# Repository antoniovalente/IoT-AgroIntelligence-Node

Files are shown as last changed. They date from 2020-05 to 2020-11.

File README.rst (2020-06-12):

IoT AgroIntelligence LoRaWAN Node
=================================

PCB files of a LoRaWAN node for agriculture use. The node uses a
`CubeCell module from Heltec <https://heltec.org/project/htcc-ab01/>`__.
The node has four 12-bit ADC channels, one 18-bit ADC channel, one I2C
port, and one SDI-12 port. It is also possible to connect a 3.6V LiPo
battery and the node has an onboard solar energy management system, that
can directly connect with a 5.5~7V solar panel.

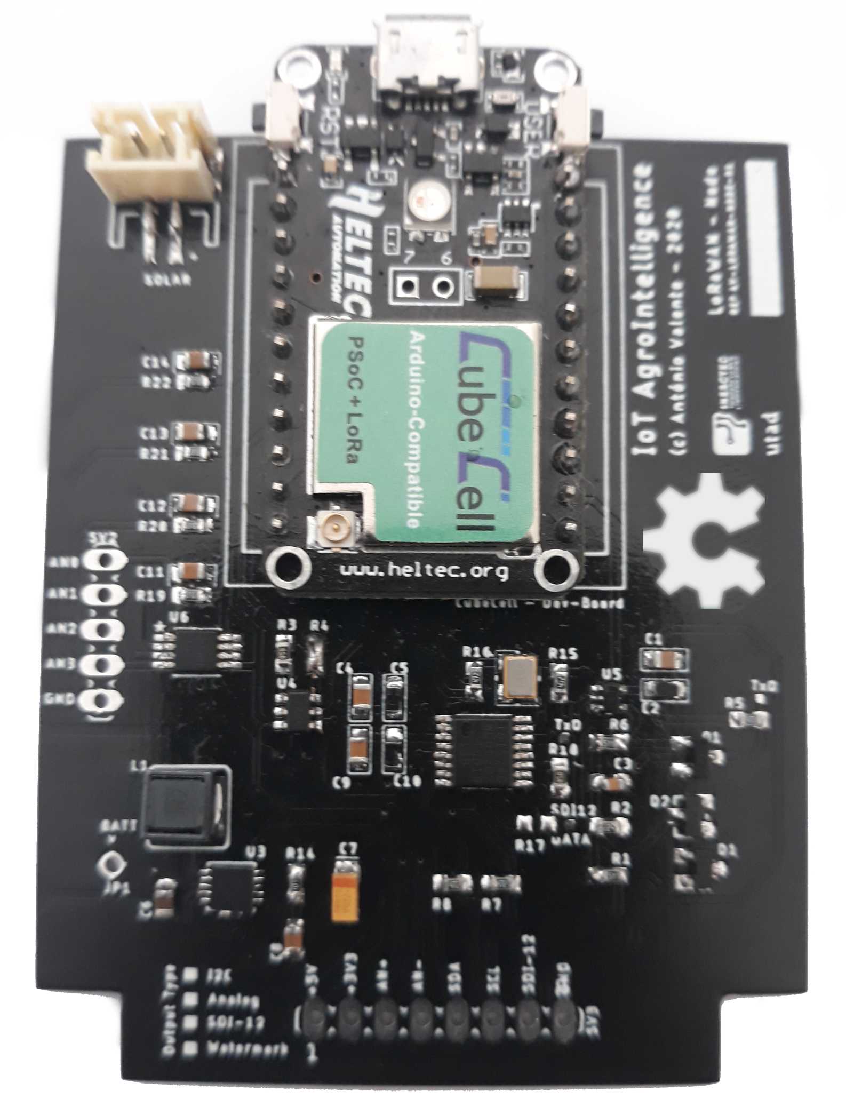
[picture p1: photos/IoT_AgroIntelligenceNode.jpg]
IoT Node


IoT Node Prerequisites
~~~~~~~~~~~~~~~~~~~~~~~

To view the files use Autodesk Eagle (project uses version 9.6.0)

`Autodesk
Eagle <https://www.autodesk.com/products/eagle/free-download>`__

Authors
-------

-  **Antonio Valente** - *Initial work* - `Antonio
   Valente <https://github.com/antoniovalente/>`__

.. raw:: html

   <!---See also the list of [contributors](https://github.com/your/project/contributors) who participated in this project. --->
   
Articles
--------
MDPI Electronics `"Low-Cost LoRaWAN Node for Agro-Intelligence IoT" <https://www.mdpi.com/741896>`__

Licenses
--------

The hardware project is licensed under the `CERN Open Hardware
Licence <https://ohwr.org/cernohl>`__ - see the
`LICENSE.md <LICENSE.md>`__ file for details.

The documentation files are licensed under a `Creative Commons
Attribution 4.0 International
License <http://creativecommons.org/licenses/by/4.0/>`__ - see the
`LICENSE-CC-BY.md <LICENSE.md>`__ file for details





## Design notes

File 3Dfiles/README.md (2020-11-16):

Boxes, lids and hoses for LoRaWAN sensor devices
================================================

BOX.stl file for 3D printing a BOX with the 1st HOSE for IoT-AgroIntelligence Node (LoRaWAN sensor node for agriculture) with solar panel and battery.

LID.stl file for 3D printing the LID for the BOX in BOX.stl.

HOSE_SENSOR_03.stl file for 3D printing the HOSE for sensors like BME680.

BOX_WisBlock.stl file for 3D printing the BOX for Wisblock board with RAK1920 (with Mickroe SDI-12 board). The BOX has two holes: TOP for antenna (RS:125-1251) and botton for EN3P4MX connector (EN3 séries Dig-Key:SC263-ND). A 18650 lithium battery holder also fits in the box.

HOSE_03.stl and HOSE_04.stl files for 3D printing the HOSES for a flexible hose to house ambient sensors (like BME680). The two files have different tolerances.

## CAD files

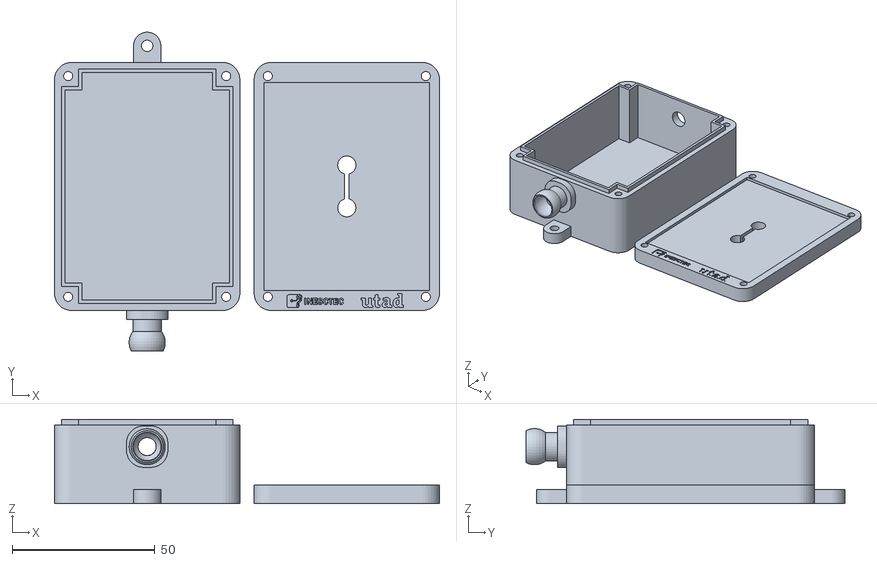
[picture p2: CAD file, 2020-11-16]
3Dfiles/CompleteBOXwoHorse.stl
135.0 x 111.7 x 29.6

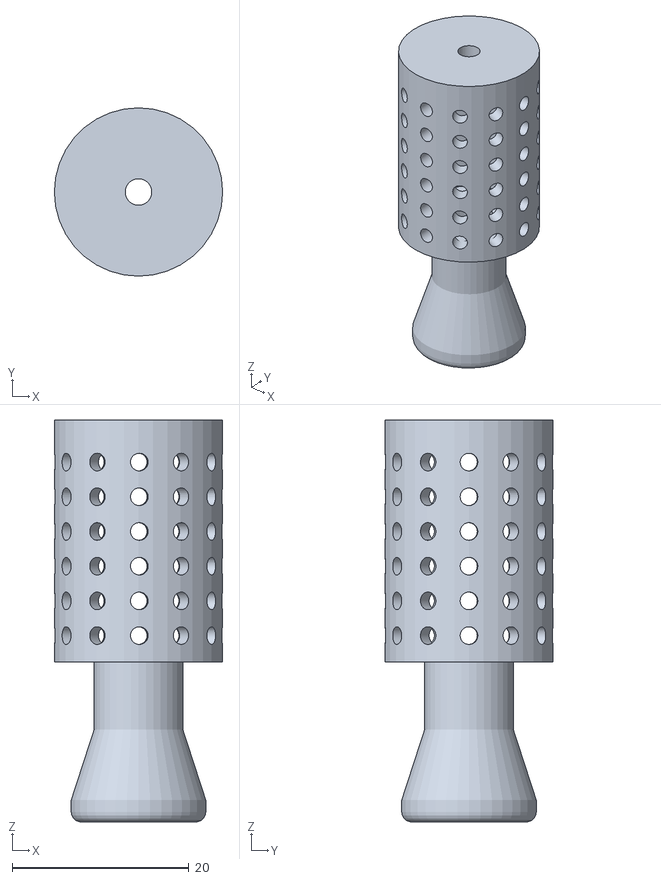
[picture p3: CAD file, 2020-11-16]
3Dfiles/HOSE_SENSOR_03.stl
19.1 x 19.1 x 45.5

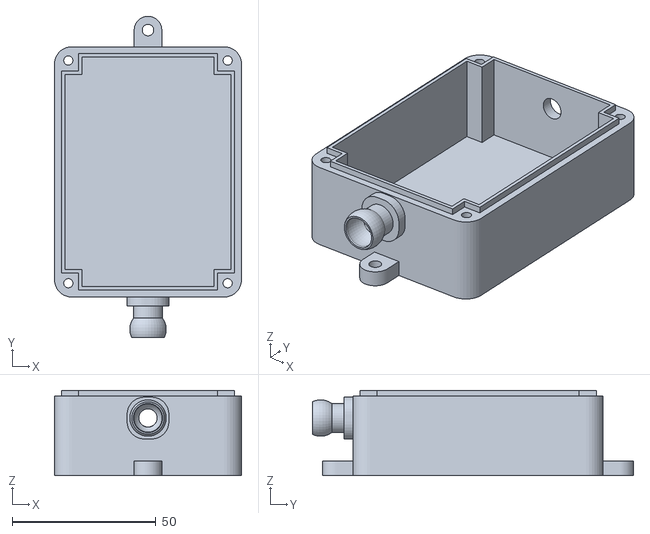
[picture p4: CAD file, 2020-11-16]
3Dfiles/BOX.stl
65.0 x 111.7 x 29.6

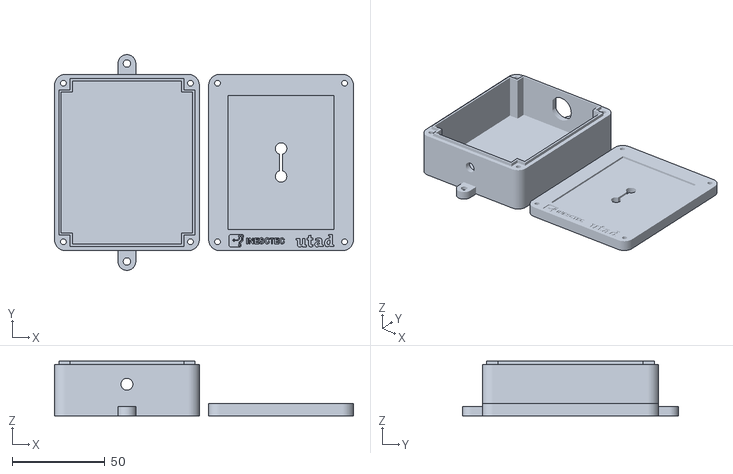
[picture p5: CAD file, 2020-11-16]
3Dfiles/BOX_WisBlock.stl
161.0 x 116.2 x 29.6

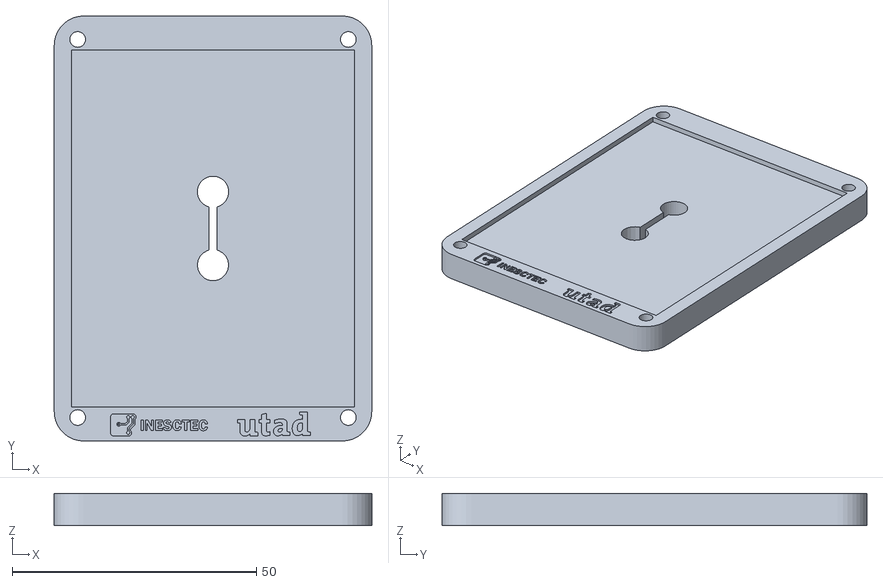
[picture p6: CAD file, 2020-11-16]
3Dfiles/LID.stl
65.0 x 87.0 x 6.60

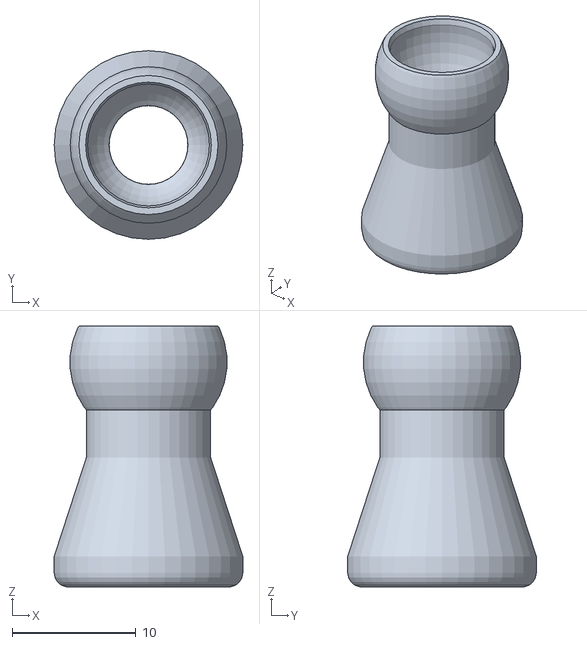
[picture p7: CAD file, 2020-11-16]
3Dfiles/HOSE_03.stl
15.2 x 15.2 x 21.1

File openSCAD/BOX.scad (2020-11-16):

include <Parametric_Modular_Hose_Library_v02/modularHoseLibrary.scad>

/* [Box Options] */
// Dimension: Box outer X-Size [mm] 72
box_Size_X          = 78;
// Dimension: Box outer Y-Size [mm]
box_Size_Y          = 95;
// Dimension: Box Inner height [mm]
box_Inner_Height    = 25;
// Box bottom/top thickness
box_BottomTop_Thickness =  2.6; // [0.6:0.2:3]
// Edge corner radius 
box_Screw_Corner_Radius   =  6; // [2:1:10]
// four outer screw hole diameters
box_Screw_Diameter     =  3.1; // [2:0.2:4]
// Box wall thickness
box_Wall_Thickness     =  3.6; // [0.4:0.2:3.2]
/* [Top Barrier Options] */
// Box barrier thickness
barrier_Thickness  =  1.2; // [0.4:0.2:3.2]
// Box barrier height
barrier_Height     =  2;   // [1.0:0.2:8]
// Additional width on the lid to correct for badly calibrated printers
barrier_Tolerance  =  0.8; // [0.0:0.1:1]
/* [Mouting Screw Nose Options] */
// Number of screw noses
screwnose_Number        = 2; // [0:No noses, 2: one top/one bottom, 4: two top/two bottom]
// Diameter of the noses' screw holes
screwnose_Diameter      = 4; // [2:0.2:8]
// Height of the noses
screwnose_Height        = 5; // [2:0.2:10]
// Wall thickness
screwnose_Wall_Thickness = 2.8; // [2:0.2:5]

// Solar panel
panel_Size_X            = 58;

panel_Size_Y            = 73;

panel_Height            = 2.5;
// **************************
// ** Calculated globals
// **************************
boxHeight = box_Inner_Height+box_BottomTop_Thickness;

module box() {
	barrier_Thickness = box_Wall_Thickness-barrier_Thickness;
	difference() {
		union() {
			// solid round box, corners
			translate([box_Screw_Corner_Radius, box_Screw_Corner_Radius, 0]) cylinder(r=box_Screw_Corner_Radius, h=boxHeight, $fn=definition); // bottom left
			translate([box_Size_X-box_Screw_Corner_Radius, box_Screw_Corner_Radius, 0]) cylinder(r=box_Screw_Corner_Radius, h=boxHeight, $fn=definition); // bottom right
			translate([box_Screw_Corner_Radius, box_Size_Y-box_Screw_Corner_Radius, 0]) cylinder(r=box_Screw_Corner_Radius, h=boxHeight, $fn=definition); // top left
			translate([box_Size_X-box_Screw_Corner_Radius, box_Size_Y-box_Screw_Corner_Radius, 0]) cylinder(r=box_Screw_Corner_Radius, h=boxHeight, $fn=definition); // bottom right
			// solid round box, inner filling
			translate([0, box_Screw_Corner_Radius, 0]) cube([box_Size_X, box_Size_Y-2*box_Screw_Corner_Radius, boxHeight]);
			translate([box_Screw_Corner_Radius, 0, 0]) cube([box_Size_X-2*box_Screw_Corner_Radius, box_Size_Y, boxHeight]);
			// solid round box, top border
			translate([barrier_Thickness, box_Screw_Corner_Radius+barrier_Thickness, 0]) cube([box_Size_X-2*barrier_Thickness, box_Size_Y-2*box_Screw_Corner_Radius-2*barrier_Thickness, boxHeight+barrier_Height]);
			translate([box_Screw_Corner_Radius+barrier_Thickness, barrier_Thickness, 0]) cube([box_Size_X-2*box_Screw_Corner_Radius-2*barrier_Thickness, box_Size_Y-2*barrier_Thickness, boxHeight+barrier_Height]);
		}
		// inner cut-out
		translate([box_Wall_Thickness, box_Screw_Corner_Radius+box_Wall_Thickness, box_BottomTop_Thickness]) cube([box_Size_X-2*box_Wall_Thickness, box_Size_Y-2*box_Screw_Corner_Radius-2*box_Wall_Thickness, boxHeight+barrier_Height]);
		translate([box_Screw_Corner_Radius+box_Wall_Thickness, box_Wall_Thickness, box_BottomTop_Thickness]) cube([box_Size_X-2*box_Screw_Corner_Radius-2*box_Wall_Thickness, box_Size_Y-2*box_Wall_Thickness, boxHeight+barrier_Height]);
		// Screw holes
		translate([(box_Screw_Corner_Radius+box_Wall_Thickness)/2,(box_Screw_Corner_Radius+box_Wall_Thickness)/2,-0.25]) cylinder(r=box_Screw_Diameter/2, h=boxHeight+0.5, $fn=definition);
		translate([(box_Screw_Corner_Radius+box_Wall_Thickness)/2,box_Size_Y-(box_Screw_Corner_Radius+box_Wall_Thickness)/2,-0.25]) cylinder(r=box_Screw_Diameter/2, h=boxHeight+0.5, $fn=definition);
		translate([box_Size_X-(box_Screw_Corner_Radius+box_Wall_Thickness)/2,(box_Screw_Corner_Radius+box_Wall_Thickness)/2,-0.25]) cylinder(r=box_Screw_Diameter/2, h=boxHeight+0.5, $fn=definition);
		translate([box_Size_X-(box_Screw_Corner_Radius+box_Wall_Thickness)/2,box_Size_Y-(box_Screw_Corner_Radius+box_Wall_Thickness)/2,-0.25]) cylinder(r=box_Screw_Diameter/2, h=boxHeight+0.5, $fn=definition);
		// **************************
		// ** YOUR OWN CUTOUTS HERE!
		// **************************
        // bottom
		cRadius = 7.8;
        yDisp = 1.5;
		translate([box_Size_X/2,(box_Wall_Thickness+0.1), box_Wall_Thickness+((boxHeight-box_Wall_Thickness)/2)+yDisp]) rotate([90,00,0]) cylinder(r=cRadius2, h=box_Wall_Thickness+0.3,$fn=definition);
        // top
		cRadius2 = 3.2;
		translate([box_Size_X/2,box_Size_Y+0.1, box_Wall_Thickness+((boxHeight-box_Wall_Thickness)/2)+yDisp]) rotate([90,00,0]) cylinder(r=cRadius, h=box_Wall_Thickness+0.2,$fn=definition);
        //cRadius3 = 6.1;
		//translate([box_Size_X/2,box_Size_Y+2.5, box_Wall_Thickness+((boxHeight-box_Wall_Thickness)/2)+yDisp]) rotate([90,00,0]) cylinder(r=cRadius3, h=box_Wall_Thickness+0.2,$fn=definition);
		// **************************
		// ** / CUTOUTS
		// **************************
	}
    translate([box_Size_X/2-12.05,box_Size_Y-box_Wall_Thickness,boxHeight/2-7]) cube([5,box_Wall_Thickness, 18]);
	// Lower nose(s)
	if (screwnose_Number==2) translate([box_Size_X/2, 0.001, 0]) mirror([0,1,0]) screwNose(screwnose_Diameter, screwnose_Height);
	if (screwnose_Number==4) {
		translate([box_Size_X*0.25, 0.001, 0]) mirror([0,1,0]) screwNose(screwnose_Diameter, screwnose_Height);
		translate([box_Size_X*0.75, 0.001, 0]) mirror([0,1,0]) screwNose(screwnose_Diameter, screwnose_Height);
	}
	// Upper nose(s)
	if (screwnose_Number==2) translate([box_Size_X/2, box_Size_Y-0.001, 0]) screwNose(screwnose_Diameter, screwnose_Height);
	if (screwnose_Number==4) {
		translate([box_Size_X*0.25, box_Size_Y-0.001, 0]) screwNose(screwnose_Diameter, screwnose_Height);
		translate([box_Size_X*0.75, box_Size_Y-0.001, 0]) screwNose(screwnose_Diameter, screwnose_Height);
	}
}
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

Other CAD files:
3Dfiles/HOSE_04.stl

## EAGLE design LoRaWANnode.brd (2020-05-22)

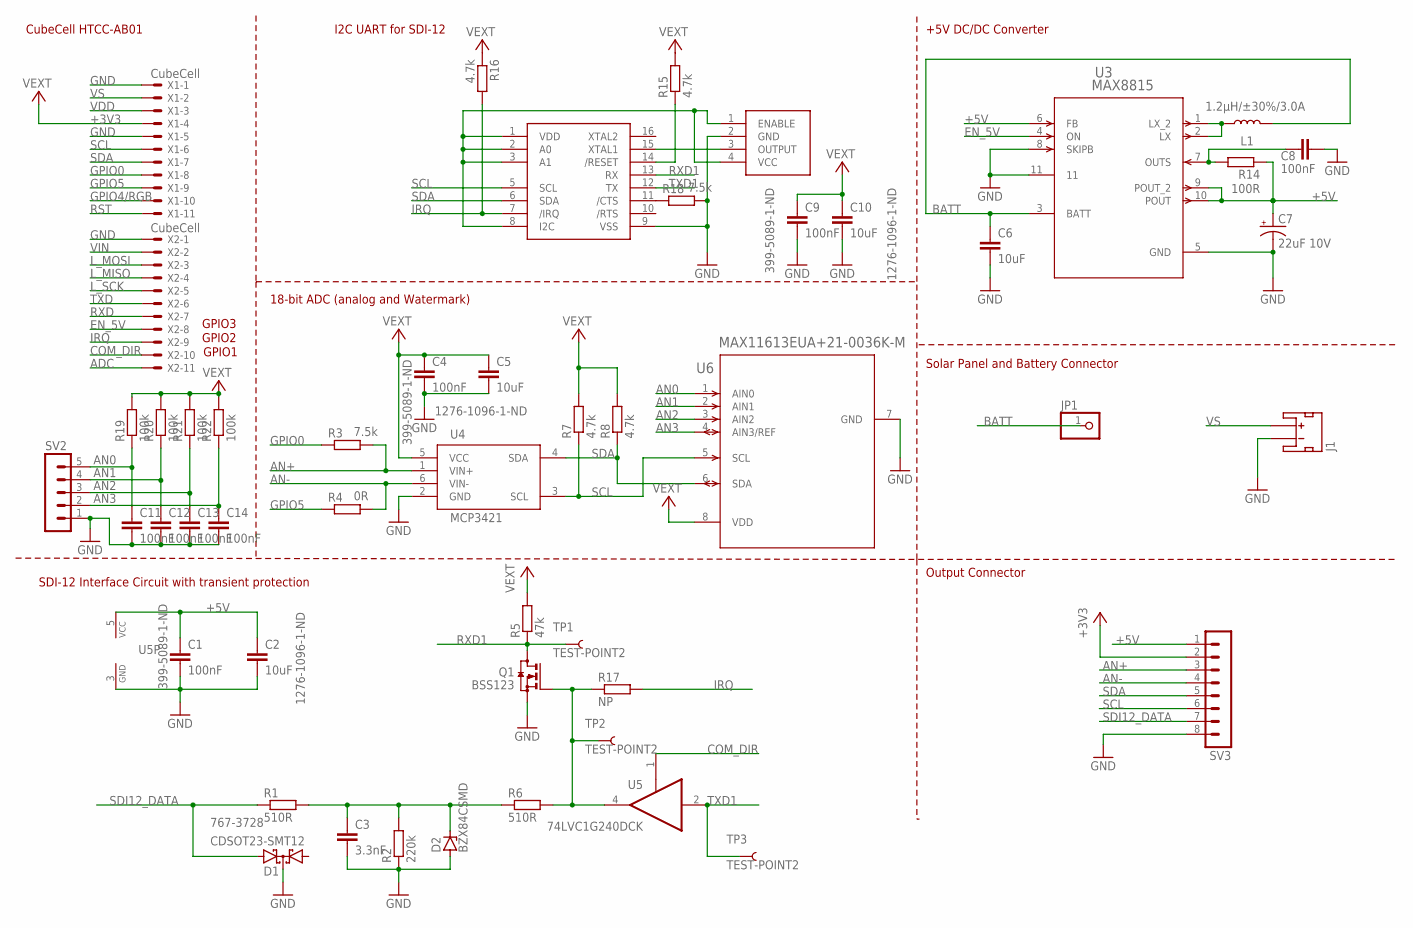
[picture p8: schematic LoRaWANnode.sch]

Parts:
C1, C4, C9, C11, C12, C13, C14: 100nF; SCHMALZHAUS_0603-CAP; MPN 06033C104KAT4A
C2, C5, C10: 10uF; SCHMALZHAUS_0603-CAP; MPN 0805ZC106KAT2A
C3: 3.3nF; C0603K
C6: 10uF; 0805
C7: 22uF 10V; EIA3216
C8: 100nF; C0603K
D1: CDSOT23-SMT12; SOT23
D2: BZX84CSMD; TO236
J1: JST_2MM_MALE; JST-2-SMD
JP1: PINHD-1X1CB; 1X01-CLEANBIG
L1: 1.2µH/±30%/3.0A; CR54
Q1: BSS123; SOT23
R1, R6: 510R; R0603
R2: 220k; R0603
R3, R18: 7.5k; R0603
R4: 0R; R0603
R5: 47k; R0603
R7, R8, R15, R16: 4.7k; R0603
R14: 100R; R0603
R17: NP; R0603
R19, R20, R21, R22: 100k; R0603
SV2: MA05-1
SV3: MA08-1
TP1, TP2, TP3: TEST-POINT2; PAD.02X.02
U1: RICKK2_SC16IS740
U2: RICKK2_OSC-KC3225K
U3: MAX8815; 21-0137I_T1033-1-M
U4: MCP3421; SOT23-6; MPN MCP3421A0T-E/CH
U5: 74LVC1G240DCK; SC70-5
U6: MAX11613EUA+21-0036K-M; 21-0036K-M
X1, X2: CubeCell; 22-23-2111

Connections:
+3V3: C4.1, C5.1, C9.1, C10.1, R5.2, R7.2, R8.2, R15.2, R16.1, R19.2, R20.2, R21.2, R22.2, SV3.2, U1.1 (VDD), U1.2 (A0), U1.3 (A1), U1.8 (I2C), U2.1 (ENABLE), U2.4 (VCC), U4.5 (VCC), U6.8 (VDD), X1.4
+5V: C1.1, C2.1, C7.+, R14.1, SV3.1, U3.6 (FB), U3.9 (POUT_2), U3.10 (POUT), U5.5 (VCC)
ADC: X2.11
AN0: C11.1, R19.1, SV2.5, U6.1 (AIN0)
AN1: C12.1, R20.1, SV2.4, U6.2 (AIN1)
AN2: C13.1, R21.1, SV2.3, U6.3 (AIN2)
AN3: C14.1, R22.1, SV2.2, U6.4 (AIN3/REF)
AN+: R3.2, SV3.3, U4.1 (VIN+)
AN-: R4.2, SV3.4, U4.6 (VIN-)
BATT: C6.1, JP1.1, L1.P$2 (2), U3.3 (BATT)
COM_DIR: U5.1 (OE), X2.10
EN_5V: U3.4 (ON), X2.8
GND: C1.2, C2.2, C3.2, C4.2, C5.2, C6.2, C7.-, C8.2, C9.2, C10.2, C11.2, C12.2, C13.2, C14.2, D1.3 (C), D2.A, J1.1 (-), Q1.2 (S), R2.1, R18.2, SV2.1, SV3.8, U1.9 (VSS), U2.2 (GND), U3.5 (GND), U3.8 (SKIPB), U3.11, U4.2 (GND), U5.3 (GND), U6.7 (GND), X1.1, X1.5, X2.1
GPIO0: R3.1, X1.8
GPIO4/RGB: X1.10
GPIO5: R4.1, X1.9
IRQ: R16.2, R17.2, U1.7 (/IRQ), X2.9
L_MISO: X2.4
L_MOSI: X2.3
L_SCK: X2.5
unnamed: C3.1, D2.C, R1.2, R2.2, R6.1
unnamed: C8.1, R14.2, U3.7 (OUTS)
unnamed: U1.15 (XTAL1), U2.3 (OUTPUT)
unnamed: L1.P$1 (1), U3.1 (LX_2), U3.2 (LX)
unnamed: R18.1, U1.11 (/CTS)
unnamed: R15.1, U1.14 (/RESET)
unnamed: Q1.1 (G), R6.2, R17.1, TP2.P$1, U5.4 (O)
RST: X1.11
RXD: X2.7
RXD1: Q1.3 (D), R5.1, TP1.P$1, U1.13 (RX)
SCL: R7.1, SV3.6, U1.5 (SCL), U4.3 (SCL), U6.5 (SCL), X1.6
SDA: R8.1, SV3.5, U1.6 (SDA), U4.4 (SDA), U6.6 (SDA), X1.7
SDI12_DATA: D1.2 (A2), R1.1, SV3.7
TXD: X2.6
TXD1: TP3.P$1, U1.12 (TX), U5.2 (I)
VDD: X1.3
VIN: X2.2
VS: J1.2 (+), X1.2

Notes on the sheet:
CubeCell HTCC-AB01
I2C UART for SDI-12
+5V DC/DC Converter
18-bit ADC (analog and Watermark)
Solar Panel and Battery Connector
Output Connector
SDI-12 Interface Circuit with transient protection
GPIO1
GPIO2
GPIO3

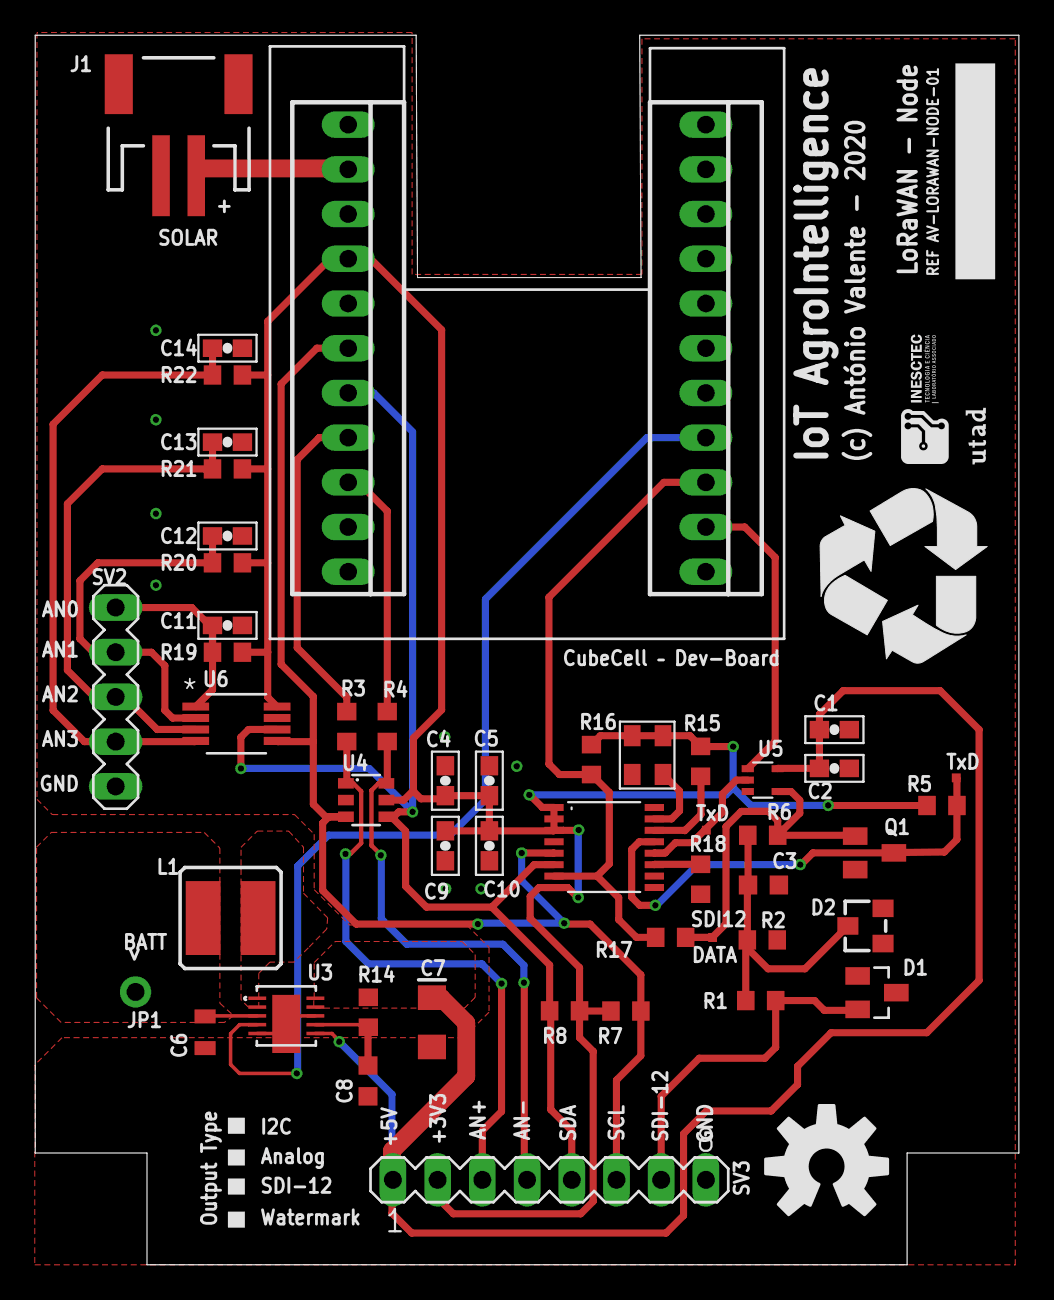
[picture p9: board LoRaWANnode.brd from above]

Board: 2 copper layers, 55.9 x 69.8 mm, 54 parts (0 on the bottom side), 28 nets.

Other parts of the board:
U$1: INESCTEC_5MM
U$2: UTAD_NEW_5MM
U$3: RECYCLING_10.00
U$4: OSHW-LOGO-L

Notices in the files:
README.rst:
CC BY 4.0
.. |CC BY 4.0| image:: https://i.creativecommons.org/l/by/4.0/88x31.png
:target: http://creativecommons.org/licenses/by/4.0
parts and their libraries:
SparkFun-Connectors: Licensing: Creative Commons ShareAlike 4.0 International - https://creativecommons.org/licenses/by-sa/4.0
